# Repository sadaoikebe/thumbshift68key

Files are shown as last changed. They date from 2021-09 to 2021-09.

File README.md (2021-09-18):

## TS69 親指シフト入力用 68% キーボード

分割3uスペースキーをもつ 68% キーボード  
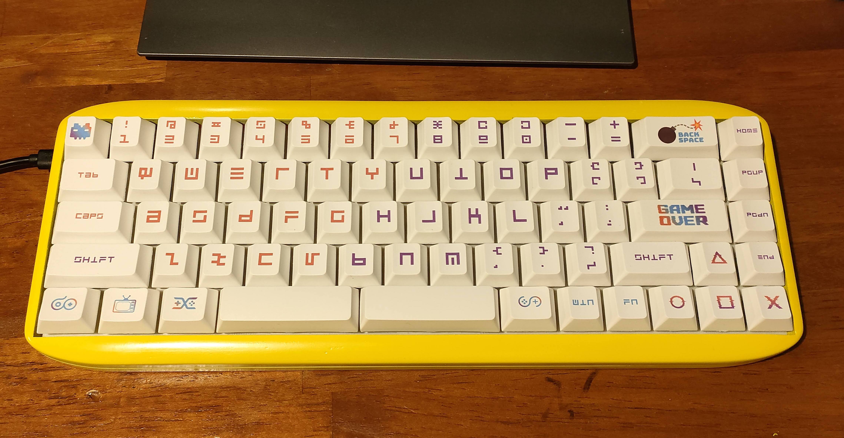
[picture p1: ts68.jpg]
完成図
  

## 必要なもの

* 基板 (製造サービスなどに発注)
* Pro Micro
* ピンヘッダ12ピン×2
* 6x 鬼目ナットM3 Aタイプ(打ち込み) 深さ5.5mm [モノタロウ](https://www.monotaro.com/p/4175/4824/)
* 6x M3キャップボルト [モノタロウ](https://www.monotaro.com/p/2901/7687/)
* 69x キースイッチ
* スタビライザー (3x2u, 2x3u)
* キーキャップ 2x 3uスペース
* ガスケット (4mm幅×2mm厚のPoronやEVAフォームなどを貼る)
* ケース 3Dプリンタ [データ](case/)
* 定位板 3Dプリンタ もしくは業者にレーザーカッティングをお願いする [データ](plate/)

Pro Microは同等品のType-Cやコンスルー版などのほうが良いかも。MicroUSB版を使うならばコネクタモゲないようにエポキシ接着剤などで補強したほうがよい  

## 製造工程

Pro Microを裏側実装する関係で、実装の順番を間違えると面倒なことになる  
1. 基板にスタビライザーを取り付け
2. 基板にピンヘッダを半田付け
3. 周辺部分のキースイッチを取り付け
4. スタビライザーの動作確認 キースイッチを取り付けてキーキャップを実際に被せてスタビライザーが気持ちよく動くか確認。プレートの精度が十分よければこの手順は必要ないけど、3Dプリンタでプレートを自作する場合、しばしばスタビライザー軸が端に触れて動きが悪くなることがある。もし動きが悪い場合プレートの精度を見直すか、あるいはスタビライザーの動作が悪いキーが嵌まる部分のプレートを削って広げて遊びを作る。
5. キースイッチを全部取り付け
6. Pro Microを取り付け
7. キーキャップを取り付け
8. ケースに入れる

## キー配置

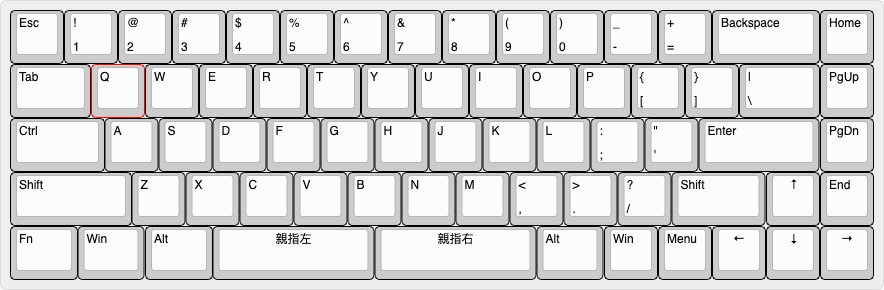
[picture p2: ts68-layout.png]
レイアウト
  
バックスペースキーの部分だけカスタマイズ可能だがそれ以外は固定。  
バックスペースキーの場所には2つのキーを割り当てて H*KBのような配置にすることもできる。  
今後親指キーに3u以外(2.75u, 2.25uなど) も使えるようにしたバージョンを作りたかったりはする。

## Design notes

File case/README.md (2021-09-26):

## TS69 case

ガスケットマウントのケース  
This design should also be scaled up with 0.26% because it was designed alongside the ts68 plate.

## CAD link

Version 2 - Round Case for t=4mm plate (need x1.0026 scaling)  
[Top&Bottom](https://www.tinkercad.com/things/h8ShuavDHmE)  

Version 3 - Square Case for t=1.5mm plate (need x1.0026 scaling)  
[Top](https://www.tinkercad.com/things/38msSLIgyYU)  
[Bottom](https://www.tinkercad.com/things/dlc2zOa5UjM)

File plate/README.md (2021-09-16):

## TS69 Plate

Please scale it up by 0.26% (x1.0026) when printing, because this board is designed with 19mm key pitch, when it should have been 19.05mm pitch (=3/4 in). (19.05/19 = 1.00263...)  
Without scaling, it will only have 304mm of total width where we need 304.8mm. 0.8mm difference makes the key on the both sides very difficult to fit.  

## CAD data

[4mm Plate for 3D Printing](https://www.tinkercad.com/things/a562PzkWgM5) (need x1.0026 scaling)  
[1.5mm Plate for laser cutting](https://www.tinkercad.com/things/d3q8ZoNIMLJ) (no need of scaling)

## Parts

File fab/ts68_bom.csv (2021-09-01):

Comment | Designator | Footprint | LCSC Part #
D_SOD-123 | D1,D2,D3,D4,D5,D6,D7,D8,D9,D10,D11,D12,D13,D14,D15,D16,D17,D18,D19,D20,D21,D22,D23,D24,D25,D26,D27,D28,D29,D30,D31,D32,D33,D34,D35,D36,D37,D38,D39,D40,D41,D42,D43,D44,D45,D46,D47,D48,D49,D50,D51,D52,D53,D54,D55,D56,D57,D58,D59,D60,D61,D62,D63,D64,D65,D66,D67,D68,D69,D70 | D_SOD-123 | C2099

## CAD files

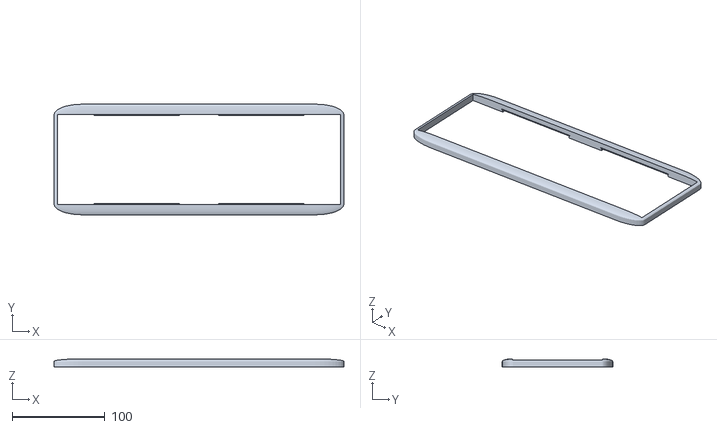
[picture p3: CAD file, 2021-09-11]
case/ts68-case-top.stl
312.0 x 119.0 x 8.99

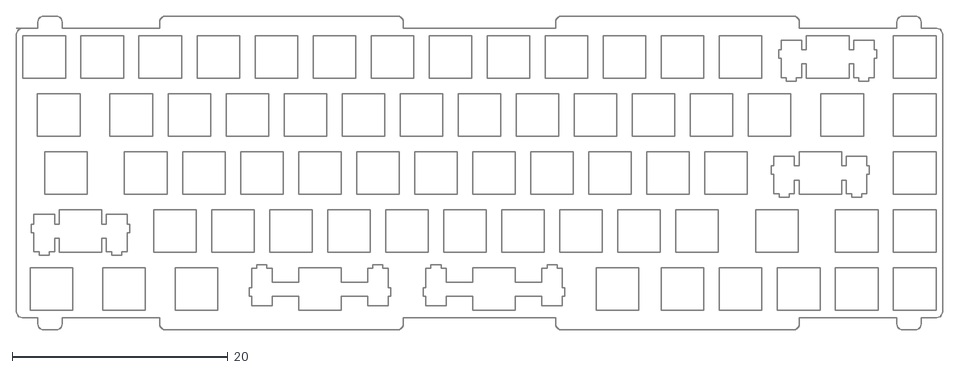
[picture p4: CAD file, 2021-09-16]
plate/ts68-plate-laser.dxf
85.8 x 29.1

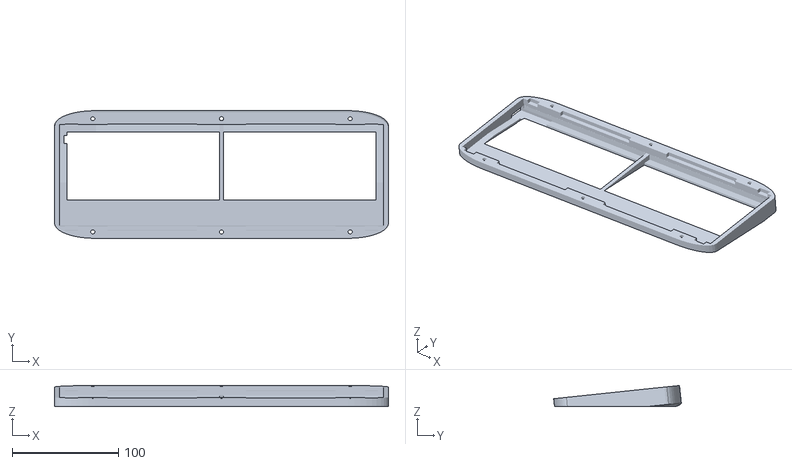
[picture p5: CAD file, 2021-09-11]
case/ts68-case-bottom.stl
314.0 x 120.1 x 19.8

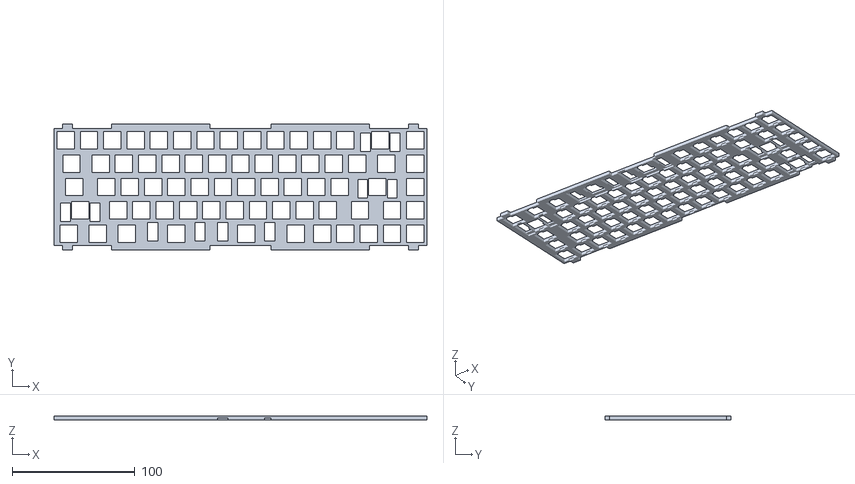
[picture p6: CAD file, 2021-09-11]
plate/ts68-plate.stl
304.0 x 103.0 x 3.00

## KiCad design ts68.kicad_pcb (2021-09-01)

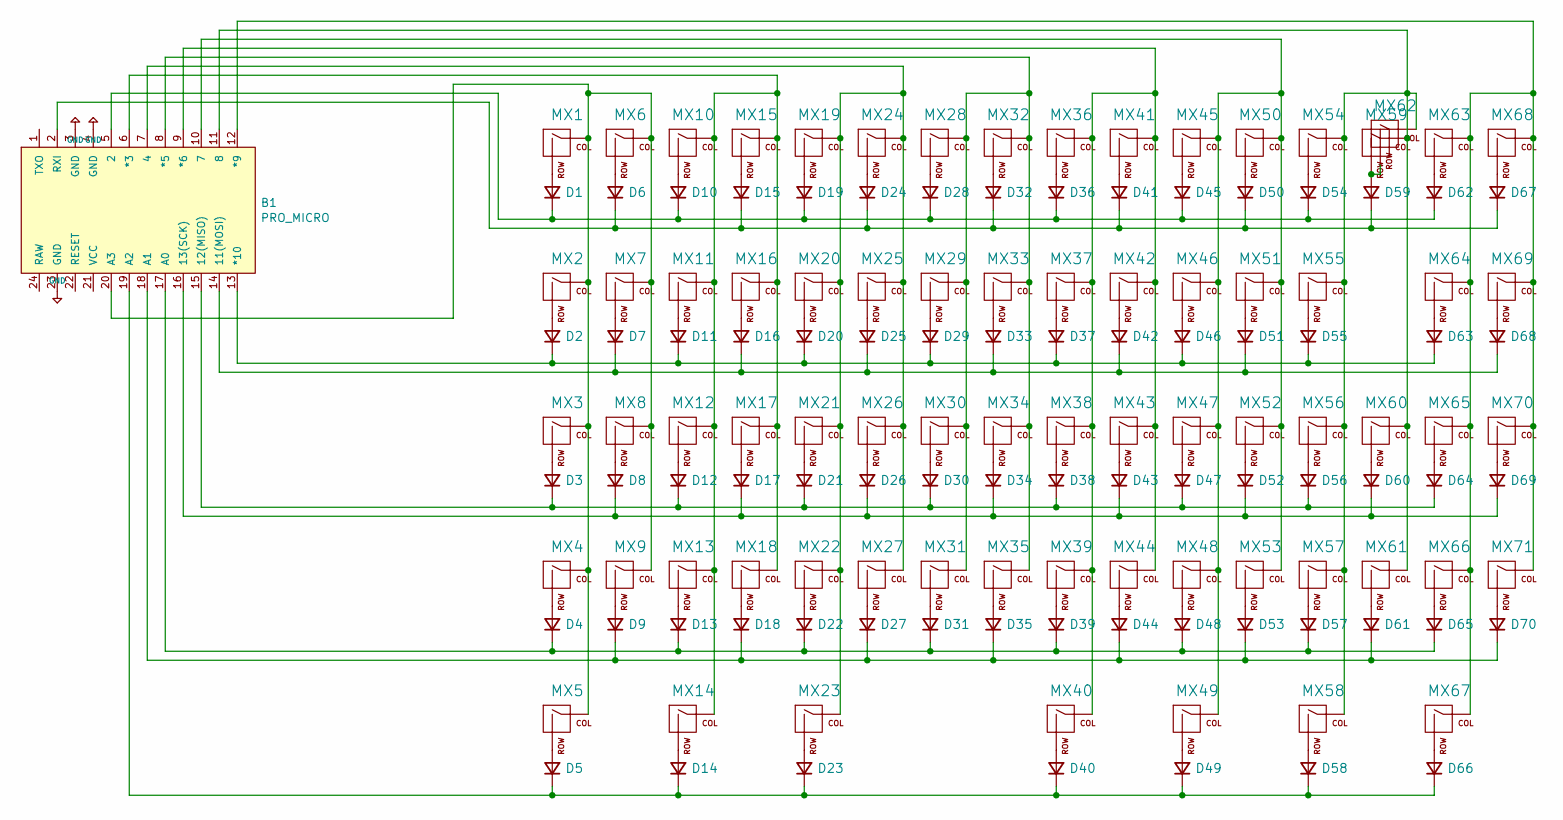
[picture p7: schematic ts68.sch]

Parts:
B1: PRO_MICRO; SPARKFUN_PRO_MICRO
D1, D2, D3, D4, D5, D6, D7, D8, D9, D10, D11, D12, D13, D14, D15, D16, D17, D18, D19, D20, D21, D22, D23, D24, D25, D26, D27, D28, D29, D30, D31, D32, D33, D34, D35, D36, D37, D38, D39, D40, D41, D42, D43, D44, D45, D46, D47, D48, D49, D50, D51, D52, D53, D54, D55, D56, D57, D58, D59, D60, D61, D62, D63, D64, D65, D66, D67, D68, D69, D70: D; D_SOD-123
MX1, MX6, MX7, MX8, MX10, MX11, MX12, MX13, MX15, MX16, MX17, MX18, MX19, MX20, MX21, MX22, MX24, MX25, MX26, MX27, MX28, MX29, MX30, MX31, MX32, MX33, MX34, MX35, MX36, MX37, MX38, MX39, MX41, MX42, MX43, MX44, MX45, MX46, MX47, MX48, MX50, MX51, MX52, MX53, MX54, MX55, MX56, MX58, MX59, MX61, MX63, MX65, MX66, MX67, MX68, MX69, MX70, MX71: MX-NoLED; MXOnly-1U-NoLED
MX2, MX64: MX-NoLED; MXOnly-1.5U-NoLED
MX3, MX57: MX-NoLED; MXOnly-1.75U-NoLED
MX4, MX60: MX-NoLED; MXOnly-2.25U-NoLED
MX5, MX9, MX14, MX49: MX-NoLED; MXOnly-1.25U-NoLED
MX23, MX40: MX-NoLED; MXOnly-3U-ReversedStabilizers-NoLED
MX62: MX-NoLED; MXOnly-2U-NoLED

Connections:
+5V: B1.3 (GND), B1.4 (GND), B1.23 (GND)
unnamed: B1.2 (RXI), D6.1 (K), D15.1 (K), D24.1 (K), D32.1 (K), D41.1 (K), D50.1 (K), D59.1 (K), D67.1 (K)
unnamed: B1.5 (2), D1.1 (K), D10.1 (K), D19.1 (K), D28.1 (K), D36.1 (K), D45.1 (K), D54.1 (K), D62.1 (K)
unnamed: B1.6 (*3), MX10.1 (COL), MX11.1 (COL), MX12.1 (COL), MX13.1 (COL), MX14.1 (COL), MX15.1 (COL), MX16.1 (COL), MX17.1 (COL), MX18.1 (COL)
unnamed: B1.7 (4), MX19.1 (COL), MX20.1 (COL), MX21.1 (COL), MX22.1 (COL), MX23.1 (COL), MX24.1 (COL), MX25.1 (COL), MX26.1 (COL), MX27.1 (COL)
unnamed: B1.8 (*5), MX28.1 (COL), MX29.1 (COL), MX30.1 (COL), MX31.1 (COL), MX32.1 (COL), MX33.1 (COL), MX34.1 (COL), MX35.1 (COL)
unnamed: B1.9 (*6), MX36.1 (COL), MX37.1 (COL), MX38.1 (COL), MX39.1 (COL), MX40.1 (COL), MX41.1 (COL), MX42.1 (COL), MX43.1 (COL), MX44.1 (COL)
unnamed: B1.10 (7), MX45.1 (COL), MX46.1 (COL), MX47.1 (COL), MX48.1 (COL), MX49.1 (COL), MX50.1 (COL), MX51.1 (COL), MX52.1 (COL), MX53.1 (COL)
unnamed: B1.11 (8), MX54.1 (COL), MX55.1 (COL), MX56.1 (COL), MX57.1 (COL), MX58.1 (COL), MX59.1 (COL), MX60.1 (COL), MX61.1 (COL), MX62.1 (COL)
unnamed: B1.12 (*9), MX63.1 (COL), MX64.1 (COL), MX65.1 (COL), MX66.1 (COL), MX67.1 (COL), MX68.1 (COL), MX69.1 (COL), MX70.1 (COL), MX71.1 (COL)
unnamed: B1.13 (*10), D2.1 (K), D11.1 (K), D20.1 (K), D29.1 (K), D37.1 (K), D46.1 (K), D55.1 (K), D63.1 (K)
unnamed: B1.14 (11(MOSI)), D7.1 (K), D16.1 (K), D25.1 (K), D33.1 (K), D42.1 (K), D51.1 (K), D68.1 (K)
unnamed: B1.15 (12(MISO)), D3.1 (K), D12.1 (K), D21.1 (K), D30.1 (K), D38.1 (K), D47.1 (K), D56.1 (K), D64.1 (K)
unnamed: B1.16 (13(SCK)), D8.1 (K), D17.1 (K), D26.1 (K), D34.1 (K), D43.1 (K), D52.1 (K), D60.1 (K), D69.1 (K)
unnamed: B1.17 (A0), D4.1 (K), D13.1 (K), D22.1 (K), D31.1 (K), D39.1 (K), D48.1 (K), D57.1 (K), D65.1 (K)
unnamed: B1.18 (A1), D9.1 (K), D18.1 (K), D27.1 (K), D35.1 (K), D44.1 (K), D53.1 (K), D61.1 (K), D70.1 (K)
unnamed: B1.19 (A2), D5.1 (K), D14.1 (K), D23.1 (K), D40.1 (K), D49.1 (K), D58.1 (K), D66.1 (K)
unnamed: B1.20 (A3), MX1.1 (COL), MX2.1 (COL), MX3.1 (COL), MX4.1 (COL), MX5.1 (COL), MX6.1 (COL), MX7.1 (COL), MX8.1 (COL), MX9.1 (COL)
unnamed: D1.2 (A), MX1.2 (ROW)
unnamed: D2.2 (A), MX2.2 (ROW)
unnamed: D3.2 (A), MX3.2 (ROW)
unnamed: D4.2 (A), MX4.2 (ROW)
unnamed: D5.2 (A), MX5.2 (ROW)
unnamed: D6.2 (A), MX6.2 (ROW)
unnamed: D7.2 (A), MX7.2 (ROW)
unnamed: D8.2 (A), MX8.2 (ROW)
unnamed: D9.2 (A), MX9.2 (ROW)
unnamed: D10.2 (A), MX10.2 (ROW)
unnamed: D11.2 (A), MX11.2 (ROW)
unnamed: D12.2 (A), MX12.2 (ROW)
unnamed: D13.2 (A), MX13.2 (ROW)
unnamed: D14.2 (A), MX14.2 (ROW)
unnamed: D15.2 (A), MX15.2 (ROW)
unnamed: D16.2 (A), MX16.2 (ROW)
unnamed: D17.2 (A), MX17.2 (ROW)
unnamed: D18.2 (A), MX18.2 (ROW)
unnamed: D19.2 (A), MX19.2 (ROW)
unnamed: D20.2 (A), MX20.2 (ROW)
unnamed: D21.2 (A), MX21.2 (ROW)
unnamed: D22.2 (A), MX22.2 (ROW)
unnamed: D23.2 (A), MX23.2 (ROW)
unnamed: D24.2 (A), MX24.2 (ROW)
unnamed: D25.2 (A), MX25.2 (ROW)
unnamed: D26.2 (A), MX26.2 (ROW)
unnamed: D27.2 (A), MX27.2 (ROW)
unnamed: D28.2 (A), MX28.2 (ROW)
unnamed: D29.2 (A), MX29.2 (ROW)
unnamed: D30.2 (A), MX30.2 (ROW)
unnamed: D31.2 (A), MX31.2 (ROW)
unnamed: D32.2 (A), MX32.2 (ROW)
unnamed: D33.2 (A), MX33.2 (ROW)
unnamed: D34.2 (A), MX34.2 (ROW)
unnamed: D35.2 (A), MX35.2 (ROW)
unnamed: D36.2 (A), MX36.2 (ROW)
unnamed: D37.2 (A), MX37.2 (ROW)
unnamed: D38.2 (A), MX38.2 (ROW)
unnamed: D39.2 (A), MX39.2 (ROW)
unnamed: D40.2 (A), MX40.2 (ROW)
unnamed: D41.2 (A), MX41.2 (ROW)
unnamed: D42.2 (A), MX42.2 (ROW)
unnamed: D43.2 (A), MX43.2 (ROW)
unnamed: D44.2 (A), MX44.2 (ROW)
unnamed: D45.2 (A), MX45.2 (ROW)
unnamed: D46.2 (A), MX46.2 (ROW)
unnamed: D47.2 (A), MX47.2 (ROW)
unnamed: D48.2 (A), MX48.2 (ROW)
unnamed: D49.2 (A), MX49.2 (ROW)
unnamed: D50.2 (A), MX50.2 (ROW)
unnamed: D51.2 (A), MX51.2 (ROW)
unnamed: D52.2 (A), MX52.2 (ROW)
unnamed: D53.2 (A), MX53.2 (ROW)
unnamed: D54.2 (A), MX54.2 (ROW)
unnamed: D55.2 (A), MX55.2 (ROW)
unnamed: D56.2 (A), MX56.2 (ROW)
unnamed: D57.2 (A), MX57.2 (ROW)
unnamed: D58.2 (A), MX58.2 (ROW)
unnamed: D59.2 (A), MX59.2 (ROW), MX62.2 (ROW)
unnamed: D60.2 (A), MX60.2 (ROW)
unnamed: D61.2 (A), MX61.2 (ROW)
unnamed: D62.2 (A), MX63.2 (ROW)
unnamed: D63.2 (A), MX64.2 (ROW)
unnamed: D64.2 (A), MX65.2 (ROW)
unnamed: D65.2 (A), MX66.2 (ROW)
unnamed: D66.2 (A), MX67.2 (ROW)
unnamed: D67.2 (A), MX68.2 (ROW)
unnamed: D68.2 (A), MX69.2 (ROW)
unnamed: D69.2 (A), MX70.2 (ROW)
unnamed: D70.2 (A), MX71.2 (ROW)

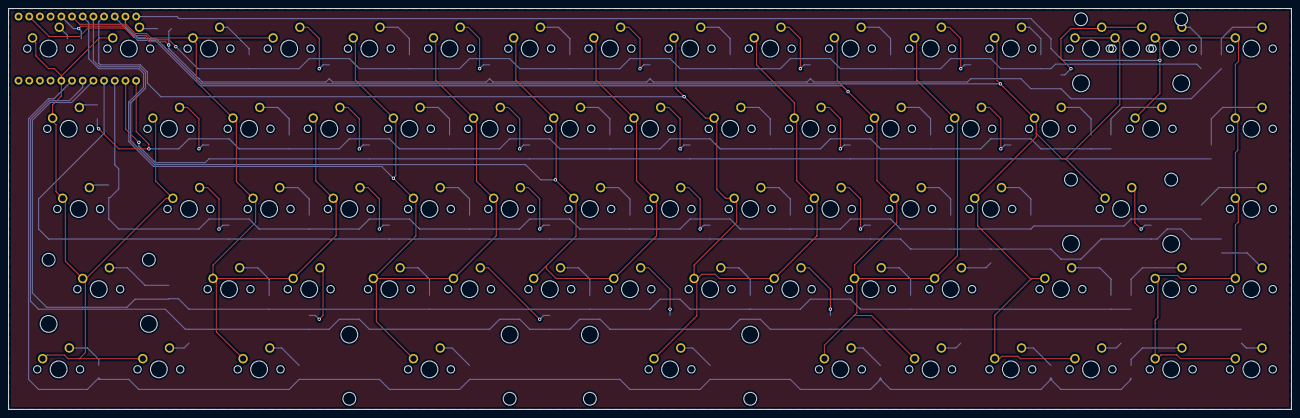
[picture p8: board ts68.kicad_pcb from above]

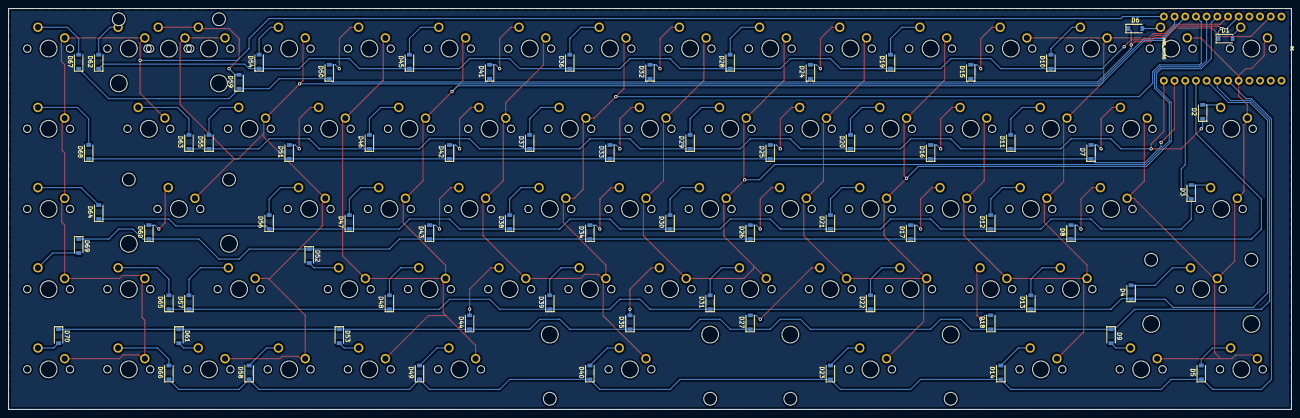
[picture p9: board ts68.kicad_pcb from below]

Board: 2 copper layers, 304.8 x 95.2 mm, 142 parts (71 on the bottom side), 88 nets.

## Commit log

2021-09-01 add plate
    [ts68-plate.stl]
2021-09-01 add case
    [ts68-case-bottom.stl, ts68-case-mid.stl, ts68-case-top.stl]
2021-09-01 tune alignment play
    [ts68-case-mid.stl, ts68-case-top.stl]
2021-09-01 bottom section thinning
    [ts68-case-bottom.stl]
2021-09-02 hole diameter
    [ts68-case-bottom.stl, ts68-case-mid.stl, ts68-case-top.stl]
2021-09-02 case inflated
    [ts68-case-bottom.stl, ts68-case-mid.stl, ts68-case-top.stl]
2021-09-02 plate inflated
    [ts68-plate.stl]
2021-09-11 first successful version
    [ts68-case-bottom.stl, ts68-case-top.stl, ts68-plate.stl]
2021-09-11 case and plate readme
2021-09-14 add laser cutting plate
2021-09-16 update documents
    [ts68-plate-laser.dxf]
2021-09-18 add link for bolts
2021-09-19 add link for version 3 case
